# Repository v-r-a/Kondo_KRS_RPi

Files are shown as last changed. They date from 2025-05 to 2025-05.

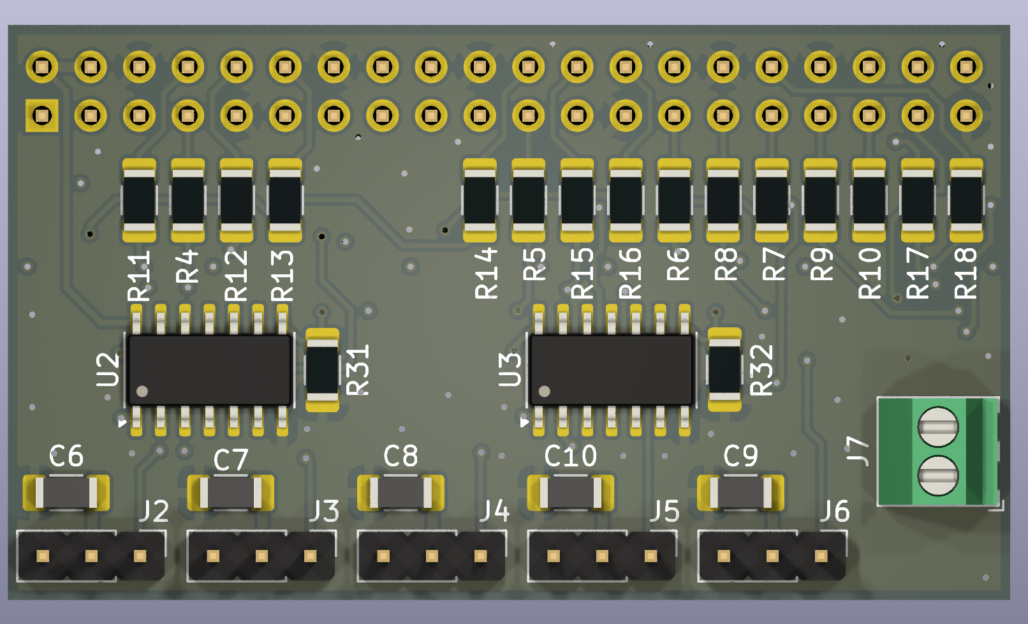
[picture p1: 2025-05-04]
hds_rpi_250121/hds_rpi_3Dtop_250121.png

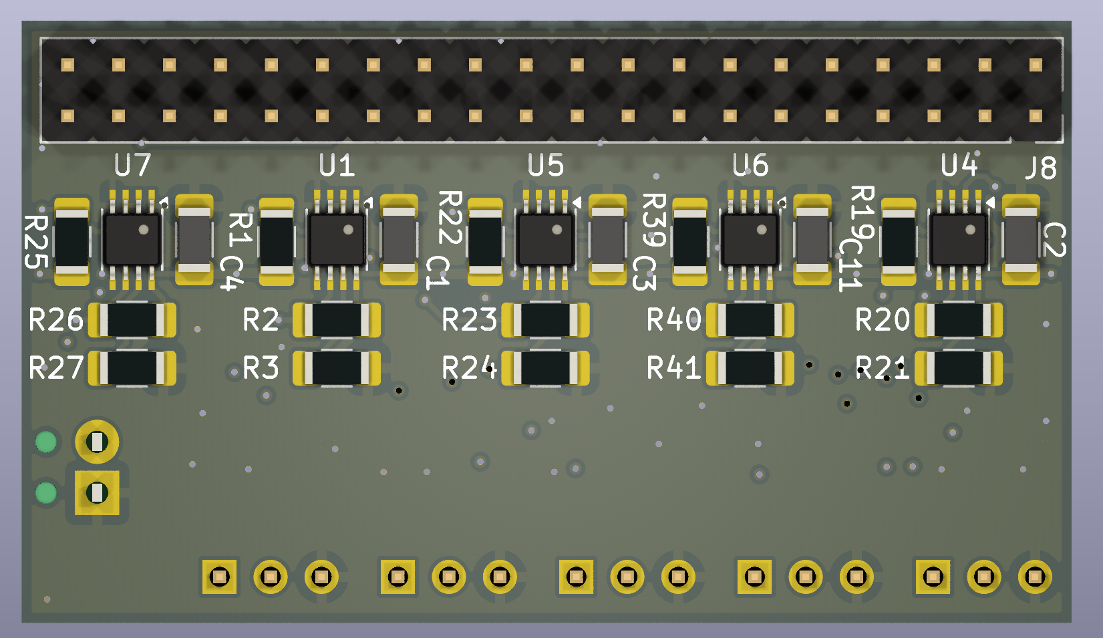
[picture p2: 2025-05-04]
hds_rpi_250121/hds_rpi_3Dbot_250121.png

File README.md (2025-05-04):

# Kondo_KRS_RPi
A Linux library for Raspberry Pi to operate the KRS motors (Kondo humanoid) using GPIO UART ports

Software dependencies: [wiringPi]([url](https://github.com/WiringPi/WiringPi))

Hardware dependencies: PCB for half-duplex communication with Kondo KRS 2552 motors. wiringPi is needed for toggling RX/TX using the tri-state buffer.

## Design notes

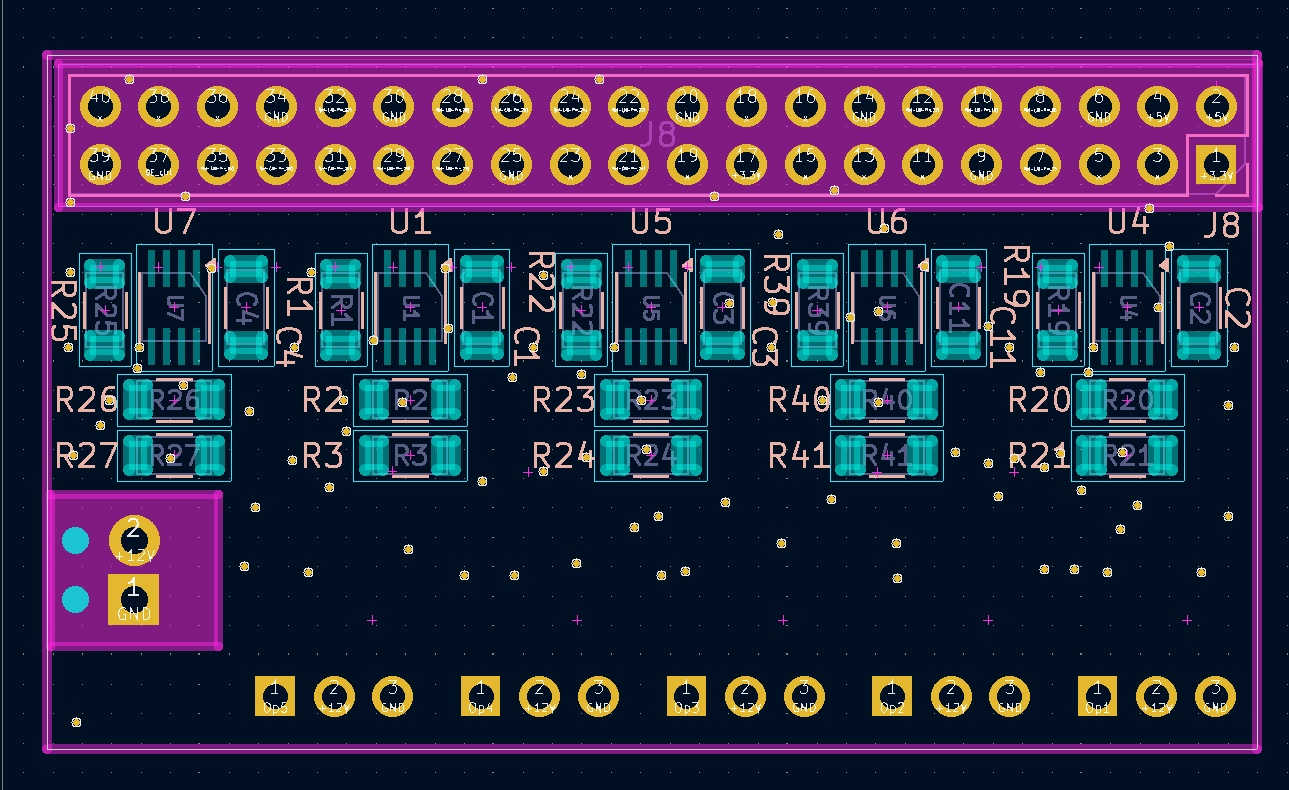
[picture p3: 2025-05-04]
hds_rpi_250121/hds_rpi_2Dbot_250121.png

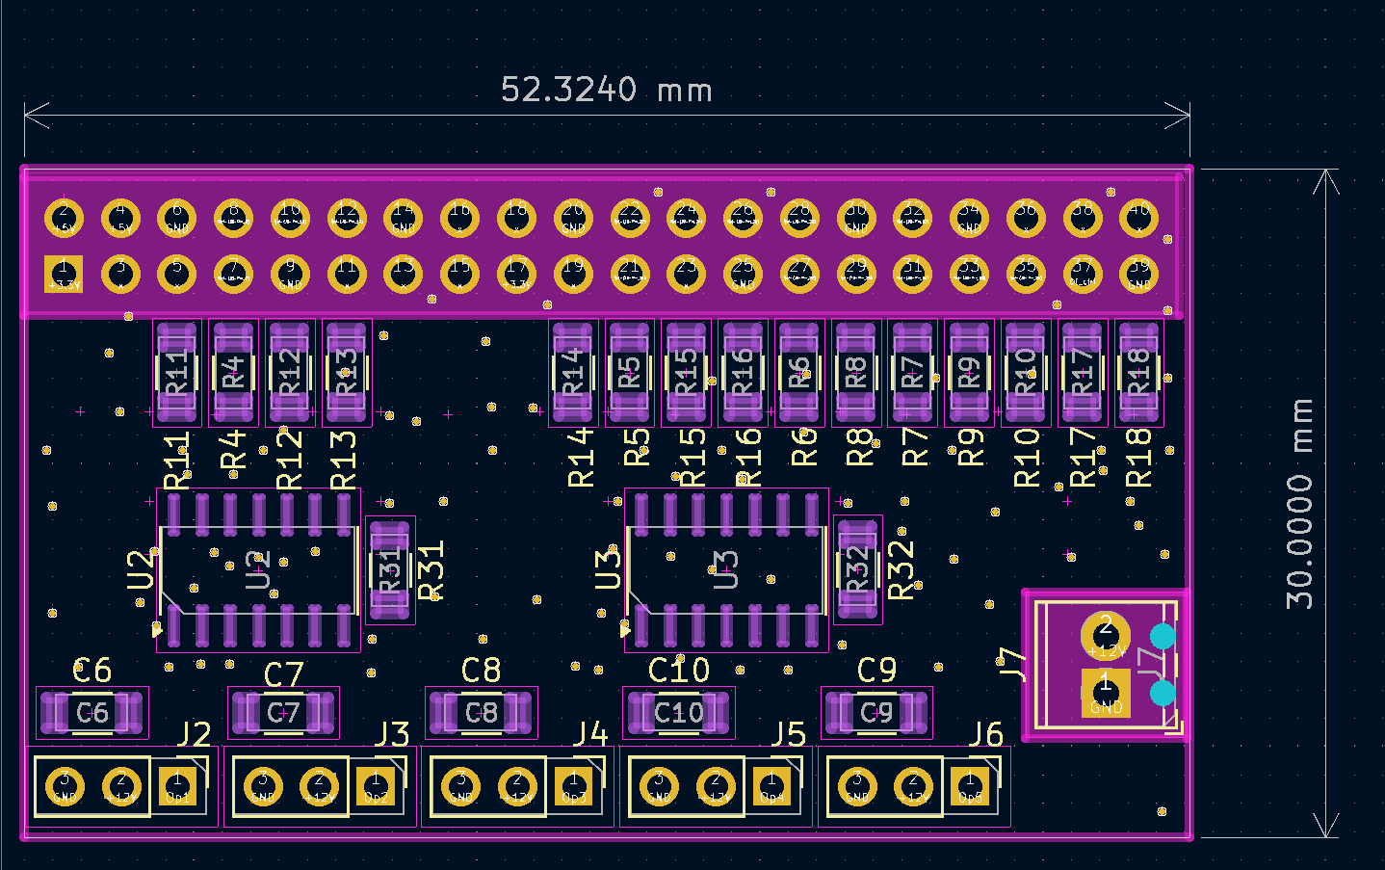
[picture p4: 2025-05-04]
hds_rpi_250121/hds_rpi_2Dtop_250121.png

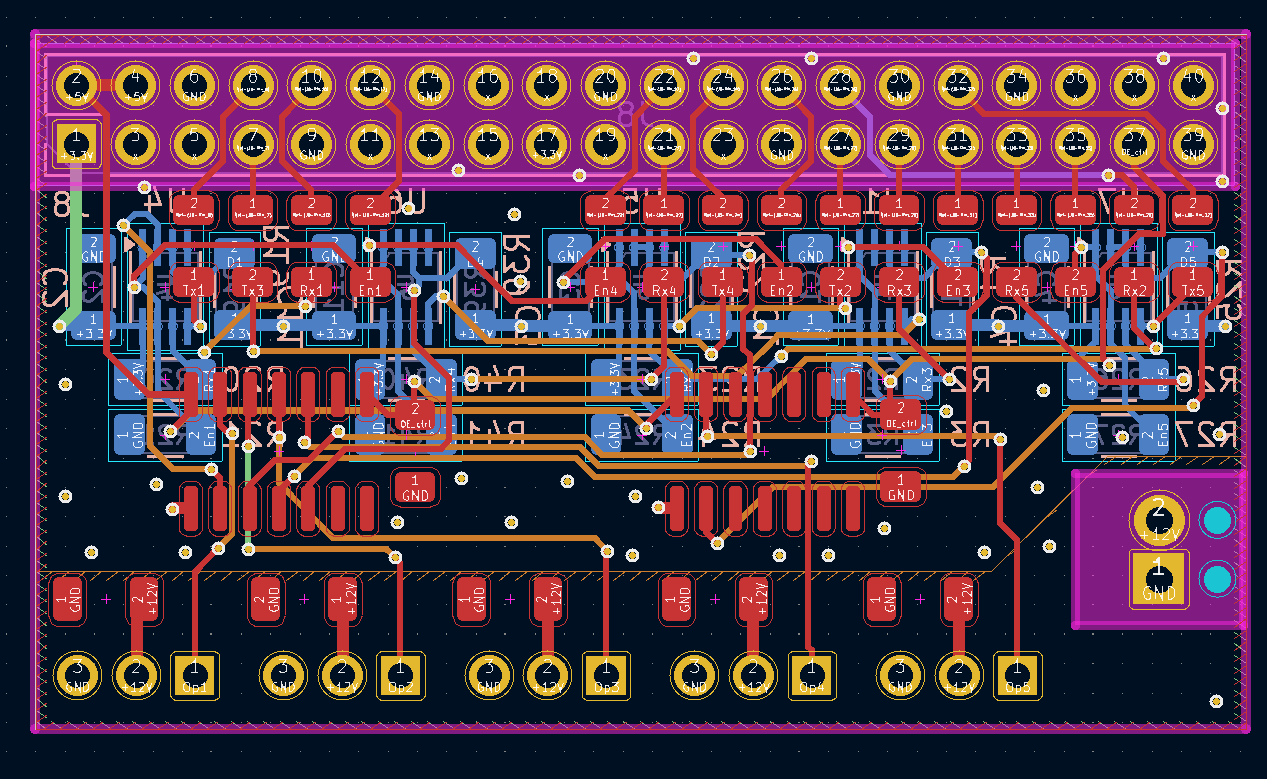
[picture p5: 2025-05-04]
hds_rpi_250121/hds_rpi_2DCU_250121.png

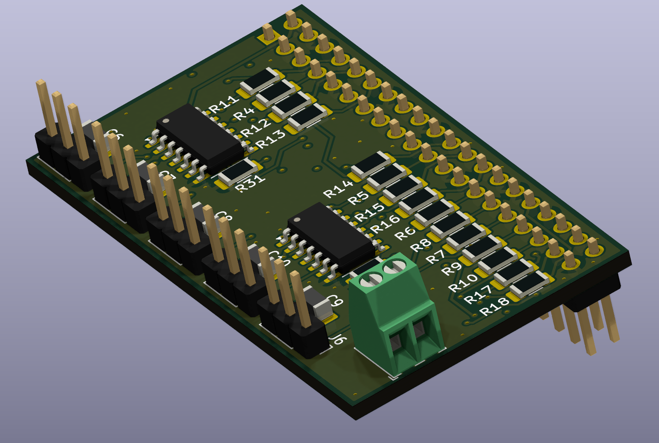
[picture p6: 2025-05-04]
hds_rpi_250121/hds_rpi_3Diso_250121.png

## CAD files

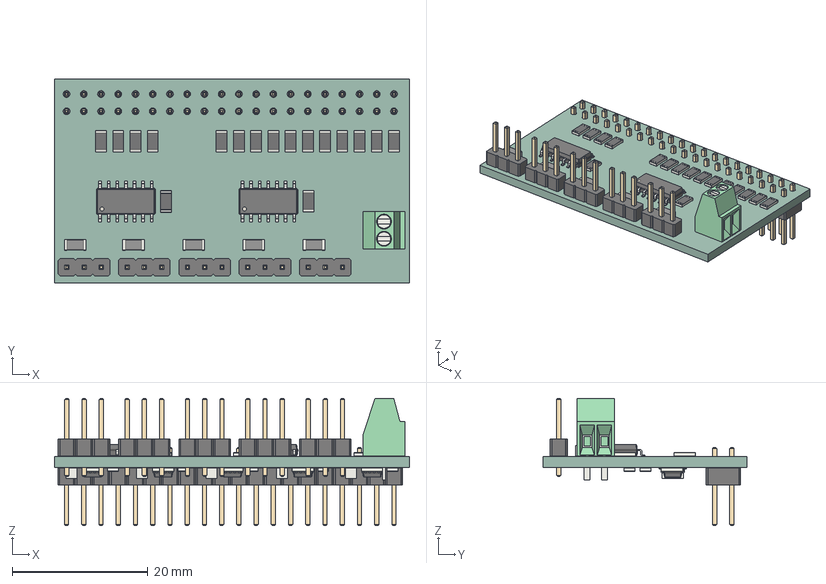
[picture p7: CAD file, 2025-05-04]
hds_rpi_250121/hds_rpi.step
52.3 x 30.0 x 18.8 mm
PinHeader_1x03_P254mm_Vertical x 5
R_1206_3216Metric x 32
L_1206_3216Metric x 10
SOIC_14_39x87mm_P127mm x 2
TerminalBlock_Phoenix_MPT_05_2_254_1x02_P254mm_Horizontal
SSOP_8_295x28mm_P065mm x 5
PinHeader_2x20_P254mm_Vertical
hds_rpi_PCB

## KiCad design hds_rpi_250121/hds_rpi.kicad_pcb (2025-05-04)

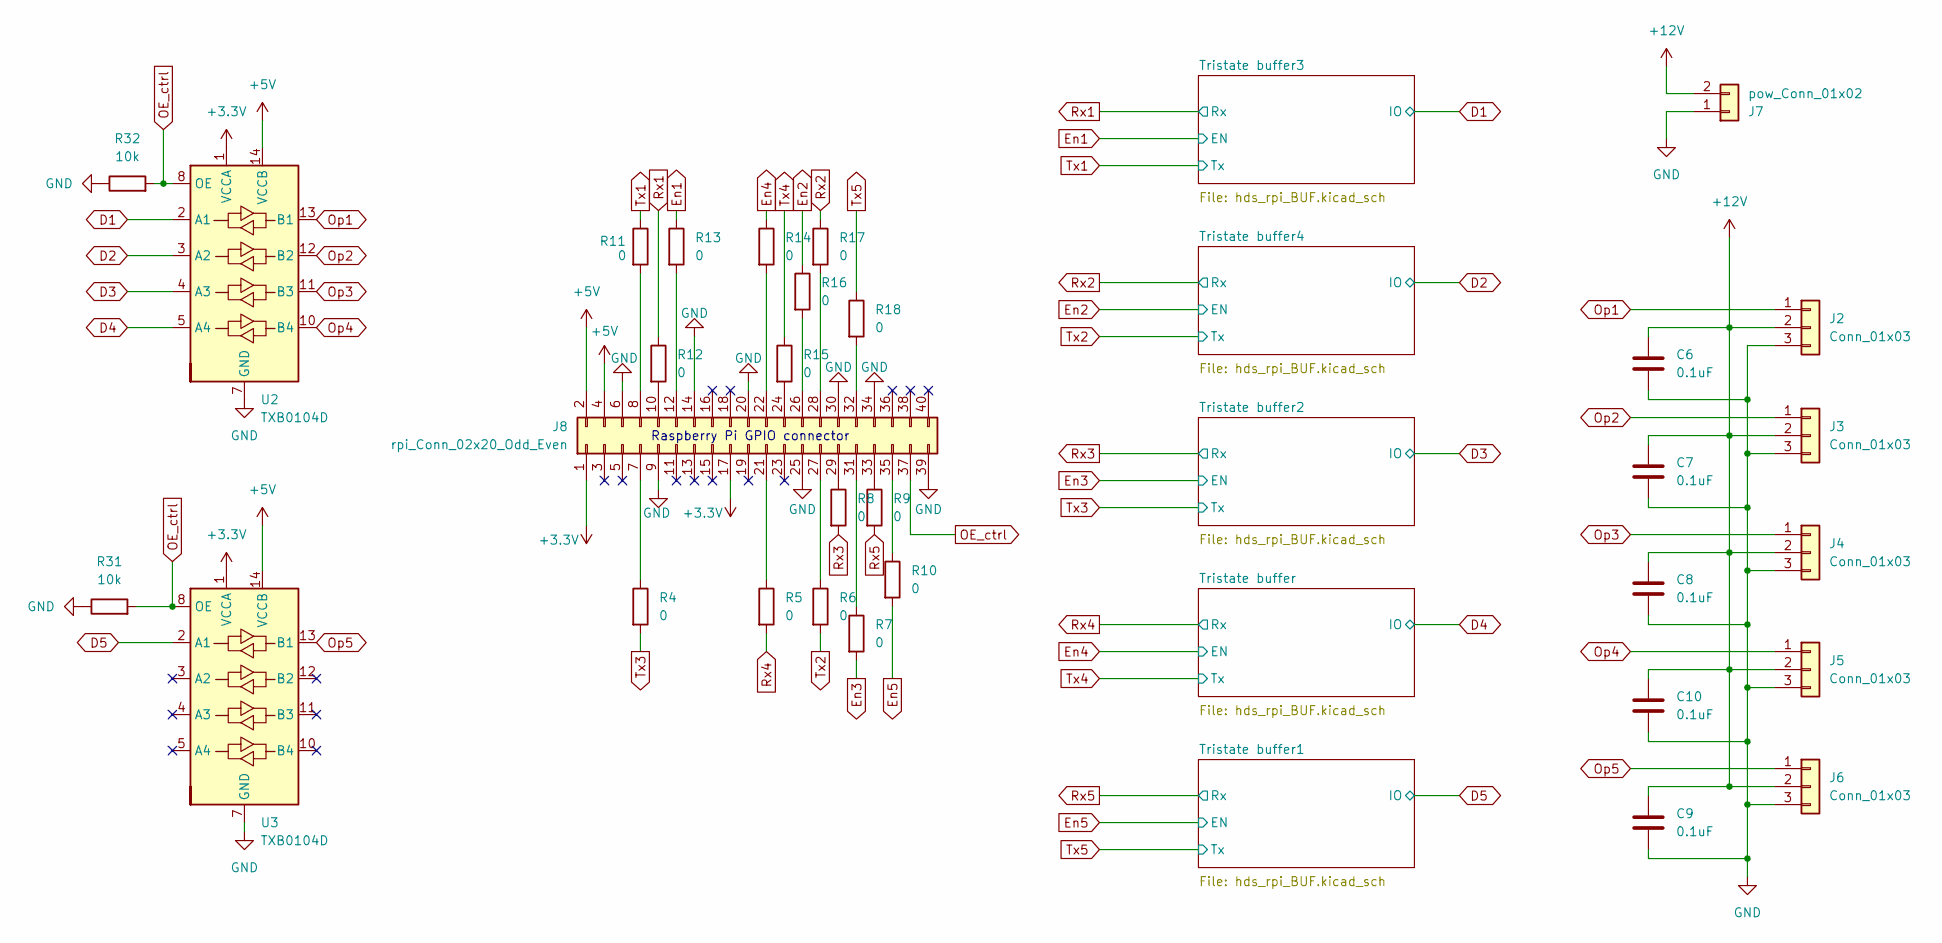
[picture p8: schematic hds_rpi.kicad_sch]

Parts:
C6, C7, C8, C9, C10: 0.1uF; L_1206_3216Metric_Pad1.22x1.90mm_HandSolder
J2, J3, J4, J5, J6: Conn_01x03; PinHeader_1x03_P2.54mm_Vertical
J7: pow_Conn_01x02; TerminalBlock_Phoenix_MPT-0,5-2-2.54_1x02_P2.54mm_Horizontal
J8: rpi_Conn_02x20_Odd_Even; Mirrored_PinHeader_2x20_P2.54mm_Vertical
R4, R5, R6, R7, R8, R9, R10, R11, R12, R13, R14, R15, R16, R17, R18: 0; R_1206_3216Metric_Pad1.30x1.75mm_HandSolder
R31, R32: 10k; R_1206_3216Metric_Pad1.30x1.75mm_HandSolder
U2, U3: TXB0104D; SOIC-14_3.9x8.7mm_P1.27mm

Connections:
+3.3V: J8.1, J8.17, U2.1 (VCCA), U3.1 (VCCA); also elsewhere on the board
+5V: J8.2, J8.4, U2.14 (VCCB), U3.14 (VCCB)
+12V: C6.2, C7.1, C8.2, C9.2, C10.2, J2.2, J3.2, J4.2, J5.2, J6.2, J7.2
D1: U2.2 (A1); also elsewhere on the board
D2: U2.3 (A2); also elsewhere on the board
D3: U2.4 (A3); also elsewhere on the board
D4: U2.5 (A4); also elsewhere on the board
D5: U3.2 (A1); also elsewhere on the board
En1: R13.1; also elsewhere on the board
En2: R16.1; also elsewhere on the board
En3: R7.2; also elsewhere on the board
En4: R14.1; also elsewhere on the board
En5: R10.2; also elsewhere on the board
GND: C6.1, C7.2, C8.1, C9.1, C10.1, J2.3, J3.3, J4.3, J5.3, J6.3, J7.1, J8.6, J8.9, J8.14, J8.20, J8.25, J8.30, J8.34, J8.39, R31.1, R32.1, U2.7 (GND), U3.7 (GND); also elsewhere on the board
unnamed: J8.7, R4.1
unnamed: J8.8, R11.2
unnamed: J8.10, R12.2
unnamed: J8.12, R13.2
unnamed: J8.21, R5.1
unnamed: J8.22, R14.2
unnamed: J8.24, R15.2
unnamed: J8.26, R16.2
unnamed: J8.27, R6.1
unnamed: J8.28, R17.2
unnamed: J8.29, R8.1
unnamed: J8.31, R7.1
unnamed: J8.32, R18.2
unnamed: J8.33, R9.1
unnamed: J8.35, R10.1
OE_ctrl: J8.37, R31.2, R32.2, U2.8 (OE), U3.8 (OE)
Op1: J2.1, U2.13 (B1)
Op2: J3.1, U2.12 (B2)
Op3: J4.1, U2.11 (B3)
Op4: J5.1, U2.10 (B4)
Op5: J6.1, U3.13 (B1)
Rx1: R12.1; also elsewhere on the board
Rx2: R17.1; also elsewhere on the board
Rx3: R8.2; also elsewhere on the board
Rx4: R5.2; also elsewhere on the board
Rx5: R9.2; also elsewhere on the board
Tx1: R11.1; also elsewhere on the board
Tx2: R6.2; also elsewhere on the board
Tx3: R4.2; also elsewhere on the board
Tx4: R15.1; also elsewhere on the board
Tx5: R18.1; also elsewhere on the board

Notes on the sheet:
Raspberry Pi GPIO connector

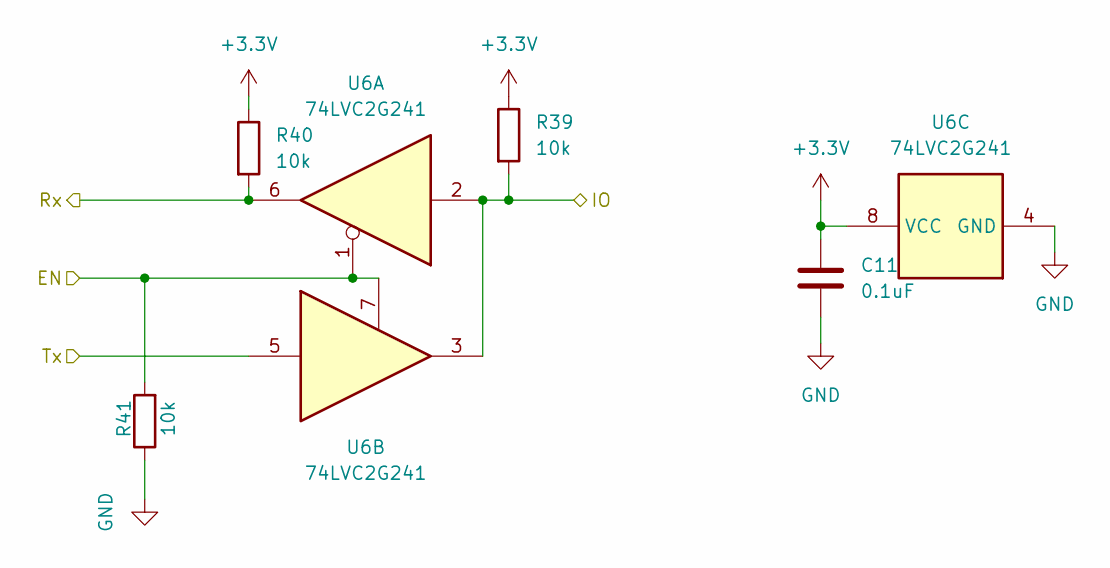
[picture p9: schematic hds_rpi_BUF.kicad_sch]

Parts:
C11: 0.1uF; L_1206_3216Metric_Pad1.22x1.90mm_HandSolder
R39, R40, R41: 10k; R_1206_3216Metric_Pad1.30x1.75mm_HandSolder
U6: 74LVC2G241; SSOP-8_2.95x2.8mm_P0.65mm

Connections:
+3.3V: C11.1, R39.1, R40.1, U6.8 (VCC); also elsewhere on the board
D4: R39.2, U6.2, U6.3; also elsewhere on the board
En4: R41.2, U6.1, U6.7; also elsewhere on the board
GND: C11.2, R41.1, U6.4 (GND); also elsewhere on the board
Rx4: R40.2, U6.6; also elsewhere on the board
Tx4: U6.5; also elsewhere on the board

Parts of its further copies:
C1, C2, C3, C4: 0.1uF; L_1206_3216Metric_Pad1.22x1.90mm_HandSolder
R1, R2, R3, R19, R20, R21, R22, R23, R24, R25, R26, R27: 10k; R_1206_3216Metric_Pad1.30x1.75mm_HandSolder
U1, U4, U5, U7: 74LVC2G241; SSOP-8_2.95x2.8mm_P0.65mm

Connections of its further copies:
+3.3V: C1.1, C2.1, C3.1, C4.1, R1.1, R2.1, R19.1, R20.1, R22.1, R23.1, R25.1, R26.1, U1.8 (VCC), U4.8 (VCC), U5.8 (VCC), U7.8 (VCC); also elsewhere on the board
D1: R19.2, U4.2, U4.3; also elsewhere on the board
D2: R22.2, U5.2, U5.3; also elsewhere on the board
D3: R1.2, U1.2, U1.3; also elsewhere on the board
D5: R25.2, U7.2, U7.3; also elsewhere on the board
En1: R21.2, U4.1, U4.7; also elsewhere on the board
En2: R24.2, U5.1, U5.7; also elsewhere on the board
En3: R3.2, U1.1, U1.7; also elsewhere on the board
En5: R27.2, U7.1, U7.7; also elsewhere on the board
GND: C1.2, C2.2, C3.2, C4.2, R3.1, R21.1, R24.1, R27.1, U1.4 (GND), U4.4 (GND), U5.4 (GND), U7.4 (GND); also elsewhere on the board
Rx1: R20.2, U4.6; also elsewhere on the board
Rx2: R23.2, U5.6; also elsewhere on the board
Rx3: R2.2, U1.6; also elsewhere on the board
Rx5: R26.2, U7.6; also elsewhere on the board
Tx1: U4.5; also elsewhere on the board
Tx2: U5.5; also elsewhere on the board
Tx3: U1.5; also elsewhere on the board
Tx5: U7.5; also elsewhere on the board

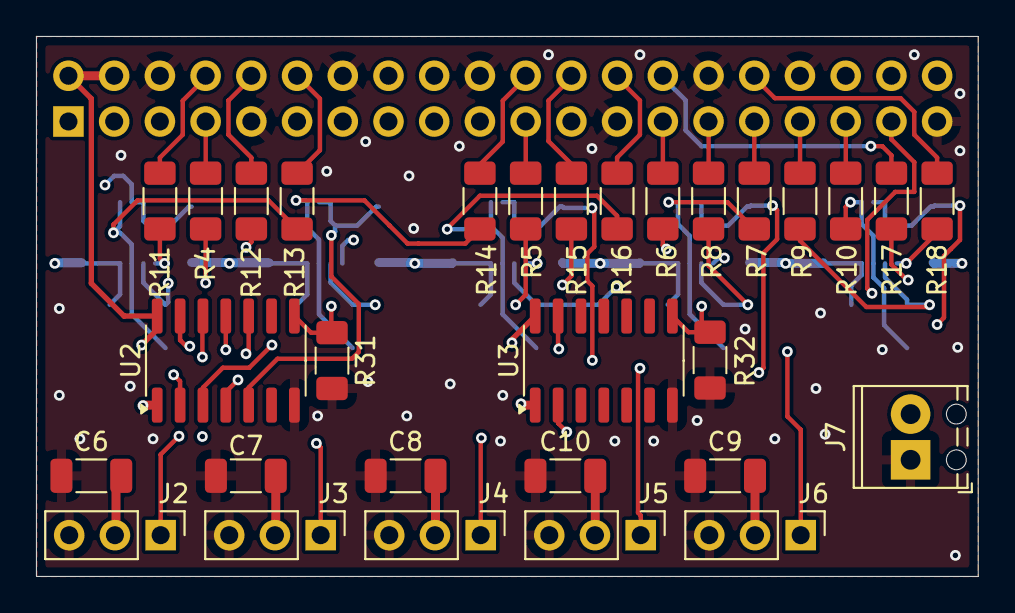
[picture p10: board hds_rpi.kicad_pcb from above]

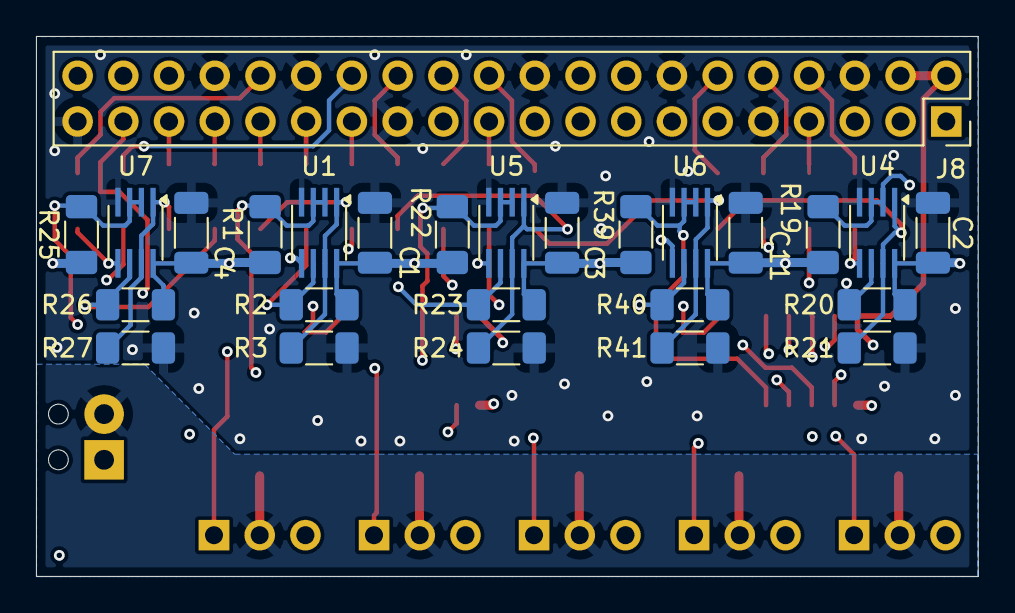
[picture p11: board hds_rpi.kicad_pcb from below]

Board: 4 copper layers, 52.3 x 30.0 mm, 56 parts (26 on the bottom side), 45 nets.

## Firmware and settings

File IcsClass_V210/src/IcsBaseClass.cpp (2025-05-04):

/**
 *	@file IcsBaseClass.cpp
 *	@brief ICS3.5/3.6 base library
 *	@author Kondo Kagaku Co.,Ltd.
 *	@date	2020/02/20
 *	@version 2.1.0
 *	@copyright &copy; Kondo Kagaku Co.,Ltd. 2017
 **/
#include <cstdio>
#include <wiringPi.h>
#include "IcsBaseClass.h"

// Servo ID range /////////////////////////////////////////////////////////////////////////////////////////////
/**
 * @brief Check if the servo ID is within range
 * @param[in] id
 * @return the ID sent
 * @retval 0xFF out of range
 **/
unsigned char IcsBaseClass::idMax(unsigned char id)
{
  if ((char)id < MIN_ID)
  {
    id = 0xFF;
  }
  if (id > MAX_ID)
  {
    id = 0xFF;
  }
  return id;
}

// Servo movable range parameter range limit setting ///////////////////////////////////////////////////////////////
/**
 * @brief Keep within the maximum and minimum value range of position data
 * @param[in] maxPos Maximum value
 * @param[in] minPos Minimum value
 * @param[in,out] val current value
 * @return Position data with limit
 **/
bool IcsBaseClass::maxMin(int maxPos, int minPos, int val)
{
  if (val > maxPos)
  {
    return false;
  }
  if (val < minPos)
  {
    return false;
  }
  return true;
}

// Angle conversion　From angle to POS/////////////////////////////////////////////////////////////////////////////////////
/**
 * @brief Convert angle data (float type) to position data
 * @param[in] deg Angle (deg) (float type)
 * @return position data
 * @retval -1 out of range
 **/
int IcsBaseClass::degPos(float deg)
{
  if (deg > MAX_DEG)
  {
    return -1;
  }
  if (deg < MIN_DEG)
  {
    return -1;
  }
  int pos = deg * 29.633;
  pos = pos + 7500;
  return pos;
}

// Angle conversion POS to angle /////////////////////////////////////////////////////////////////////////////////////
/**
 * @brief Convert position data to angle data (float type)
 * @param[in] pos position data
 * @return Angle (deg) (float type)
 * @retval #ANGLE_F_FALSE Out of range in positive direction
 * @retval -#ANGLE_F_FALSE (0x8000) Out of range in negative direction
 **/
float IcsBaseClass::posDeg(int pos)
{
  pos = pos - 7500;
  float deg = pos / 29.633;

  if (deg > MAX_DEG)
  {
    return ANGLE_F_FALSE;
  }
  if (deg < MIN_DEG)
  {
    return -ANGLE_F_FALSE;
  }

  return deg;
}

// Angle conversion x100 Angle to POS///////////////////////////////////////////////////////////////////////////////
/**
 * @brief Convert angle data x100 (int type) to position data
 * @param[in] deg Angle (deg x100) (int type)
 * @return Converted position data
 * @retval -1 out of range
 **/
int IcsBaseClass::degPos100(int deg)
{
  if (deg > MAX_100DEG)
  {
    return -1;
  }
  if (deg < MIN_100DEG)
  {
    return -1;
  }
  long a = ((long)deg * 2963) / 10000;
  int pos = a + 7500;
  return pos;
}

// Angle conversion x100 POS to angle///////////////////////////////////////////////////////////////////////////////
/**
 * @brief Convert position data to angle data (int type)
 * @param[in] pos position data
 * @return Angle (deg x100) (int type)
 * @retval #ANGLE_I_FALSE Out of range in positive direction
 * @retval -#ANGLE_I_FALSE Out of range in negative direction
 **/
int IcsBaseClass::posDeg100(int pos)
{
  long a = pos - 7500;
  int deg = (a * 1000) / 296;

  if (deg > MAX_100DEG)
  {
    return ANGLE_I_FALSE;
  }
  if (deg < MIN_100DEG)
  {
    return -ANGLE_I_FALSE;
  }
  return deg;
}

// Servo angle set //////////////////////////////////////////////////////////////////////////////////////////
/**
 * @brief Change the angle of the servo motor
 * @param[in] id Servo motor ID number
 * @param[in] pos position data
 * @return position data
 * @retval -1 out of range, communication failure
 **/
int IcsBaseClass::setPos(unsigned char id, unsigned int pos)
{
  unsigned char txCmd[3];
  unsigned char rxCmd[3];
  unsigned int rePos;
  bool flg;

  if ((id != idMax(id)) || (!maxMin(MAX_POS, MIN_POS, pos))) // When out of range
  {
    return ICS_FALSE;
  }

  txCmd[0] = 0x80 + id;             // CMD
  txCmd[1] = ((pos >> 7) & 0x007F); // POS_H
  txCmd[2] = (pos & 0x007F);        // POS_L

  // sending and receiving
  flg = synchronize(txCmd, sizeof txCmd, rxCmd, sizeof rxCmd);
  if (flg == false)
  {
    return ICS_FALSE;
  }

  rePos = ((rxCmd[1] << 7) & 0x3F80) + (rxCmd[2] & 0x007F);

  return rePos;
}

// Servo free mode ///////////////////////////////////////////////////////////////////////////////////////
/**
 * @brief Sets the servo motor to a free (weak) state.
 * @param[in] id Servo motor ID number
 * @return position data
 * @retval -1 out of range, communication failure
 **/
int IcsBaseClass::setFree(unsigned char id)
{
  unsigned char txCmd[3];
  unsigned char rxCmd[3];
  unsigned int rePos;
  bool flg;

  if (id != idMax(id)) // When out of range
  {
    return ICS_FALSE;
  }

  txCmd[0] = 0x80 + id; // CMD
  txCmd[1] = 0;
  txCmd[2] = 0;

  // sending and receiving
  flg = synchronize(txCmd, sizeof txCmd, rxCmd, sizeof rxCmd);
  if (flg == false)
  {
    return ICS_FALSE;
  }

  rePos = ((rxCmd[1] << 7) & 0x3F80) + (rxCmd[2] & 0x007F);

  return rePos;
}

// Stretch value write 1 to 127 /////////////////////////////////////////////////////////////////////////////////
/**
 * @brief Write the servo motor stretch (holding force) value
 * @param[in] id Servo motor ID number
 * @param[in] strc Stretch data (1 to 127)
 * @return Written stretch data
 * @retval -1 Communication failure
 * @note Stretch writing 1-127 1 (weak) 127 (strong)
 **/
int IcsBaseClass::setStrc(unsigned char id, unsigned int strc)
{
  unsigned char txCmd[3];
  unsigned char rxCmd[3];
  unsigned int reData;
  bool flg;

  if ((id != idMax(id)) || (!maxMin(MAX_127, MIN_1, strc))) // When out of range
  {
    return ICS_FALSE;
  }

  txCmd[0] = 0xC0 + id; // CMD
  txCmd[1] = 0x01;      // SC stretch
  txCmd[2] = strc;      // stretch

  // sending and receiving
  flg = synchronize(txCmd, sizeof txCmd, rxCmd, sizeof rxCmd);
  if (flg == false)
  {
    return ICS_FALSE;
  }
  reData = rxCmd[2];

  return reData;
}

// Speed value writing 1 to 127 ///////////////////////////////////////////////////////////////////////////////////
/**
 * @brief Change the speed (output) of the servo motor
 * @param[in] id Servo motor ID number
 * @param[in] spd Speed data (1 to 127)
 * @return Written speed data
 * @retval -1 Communication failure
 * @note Speed writing 1-127 1(slow) 127(fast)
 **/
int IcsBaseClass::setSpd(unsigned char id, unsigned int spd)
{
  unsigned char txCmd[3];
  unsigned char rxCmd[3];
  unsigned int reData;
  bool flg;

  if ((id != idMax(id)) || (!maxMin(MAX_127, MIN_1, spd))) // When out of range
  {
    return ICS_FALSE;
  }

  txCmd[0] = 0xC0 + id; // CMD
  txCmd[1] = 0x02;      // SC speed
  txCmd[2] = spd;       // speed

  // sending and receiving
  flg = synchronize(txCmd, sizeof txCmd, rxCmd, sizeof rxCmd);
  if (flg == false)
  {
    return ICS_FALSE;
  }

  reData = rxCmd[2];

  return reData;
}
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

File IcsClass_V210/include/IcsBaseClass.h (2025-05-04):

/**
*@file IcsBaseClass.h
*@brief ICS3.5/3.6 bace library header file
*@author Kondo Kagaku Co.,Ltd.
*@date 2017/12/27
*@version 2.1.0
*@copyright Kondo Kagaku Co., Ltd. 2020

*@mainpage Overview of IcsClass
*This library is for operating Kondo Scientific robot servos (KRS series). <br>
*Compatible with ICS3.5 and ICS3.6. <br>
*Currently designed to be used with Arduino products. <br>
*For usage and details, please see our website below. <br>
*<A HREF="http://kondo-robot.com/">http://kondo-robot.com/</A><br>
*If you have any problems, please contact us by referring to our website. <br>

*@par change history
*@par 2020/02/20 Ver 2.1.0
*-Change getStr in keywords.txt to getStrc
*-Change synchronize from protected to public //Because I wanted to use it externally
*-Implementation of ID command
*@par 2017/12/27 ver 2.0.0
*-Separate the communication part of ICSClass. Create IcsBaseClass.
*-"IcsHardSerialClass" which uses Serial
*<br> Derive "IcsSoftSerialClass" from IcsBaseClass using SoftSerial
*-Since SoftSerial could not use parity and the timing did not match, I created "KoCustomSoftSerial"
*@par 2016/12/27　ver 1.0.0
*-Initial distribution
**/

#ifndef __ics_Base_Servo_h__
#define __ics_Base_Servo_h__

// IcsBaseClass class ////////////////////////////////////////////////////
/**
 *@class IcsBaseClass
 *@brief Kondo Scientific's ICS 3.5/3.6 Base class for operating servo motors via microcontroller
 *@brief Create a base class to use Raspberry Pi UART
 **/
class IcsBaseClass
{
  // Fixed value (published)
public:
  // Servo ID range //////////////////////////////////////
  static constexpr int MAX_ID = 31; ///< Maximum value of servo ID
  static constexpr int MIN_ID = 0;  ///< Minimum value of servo ID

  // Servo maximum and minimum limit values

  static constexpr int MAX_POS = 11500; ///< Servo position maximum value

  static constexpr int MIN_POS = 3500; ///< Servo position minimum value
  static constexpr int ICS_FALSE = -1; ///< Value when ICS communication etc. fails

  // Fixed value (undisclosed)
protected:
  static constexpr float ANGLE_F_FALSE = 9999.9; ///< When calculating the angle, if it is not within the range, set it to 999.9 (if it is on the negative side, add a minus)
  static constexpr int ANGLE_I_FALSE = 0x7FFF;   ///< When calculating the angle, if it is not within the range, set it to 0x7FFF (if it is on the negative side, add a minus)

  // Each parameter setting range
  static constexpr int MAX_127 = 127; ///< Maximum value of parameter

  static constexpr int MAX_63 = 63; ///< Maximum value of parameter (current value)

  static constexpr int MIN_1 = 1;         ///< Minimum value of parameter
                                          // static const float MAX_DEG = 135.0;
  static constexpr float MAX_DEG = 180.0; ///< Maximum value of angle

  // static const float MIN_DEG = -135.0;
  static constexpr float MIN_DEG = -180.0; ///< Maximum value of angle

  // static const int MAX_100DEG = 13500;
  static constexpr int MAX_100DEG = 18000; ///< Maximum value of angle (x100)

  // static const int MIN_100DEG = -13500;
  static constexpr int MIN_100DEG = -18000; ///< Minimum value of angle (x100)

  // type definition in class
public:
  // constructor, destructor
  virtual ~IcsBaseClass() {}

public:
  // constructor

  // variable
public:
protected:
  // function

  // data transmission/reception
public:
  // Data transmission/reception //////////////////////////////////////////////////////////////////////////////////////////////
  /**
   *@brief Sending and receiving ICS communication
   *@param[in,out] *txBuf
   *@param[in] txLen
   *@param[out] *rxBuf Receive storage buffer
   *@param[in] rxLen Number of received data
   *@retval true Communication successful
   *@retval false Communication failure
   *@attention Please note that the number of sent data and received data varies depending on the command.
   *@attention This function must be written externally.
   **/
  virtual bool synchronize(unsigned char *txBuf, unsigned char txLen, unsigned char *rxBuf, unsigned char rxLen) = 0;

  // servo related
public:
  // Servo positioning settings
  int setPos(unsigned char id, unsigned int pos); // Target value setting
  int setFree(unsigned char id);                  // Servo weakness + reading current value

  // Write various parameters
  int setStrc(unsigned char id, unsigned int strc);  // Stretch writing 1 to 127 1 (weak) <=> 127 (strong)
  int setSpd(unsigned char id, unsigned int spd);    // Speed writing 1 to 127 1(slow) <=> 127(fast)
  int setCur(unsigned char id, unsigned int curlim); // Write current limit value 1 to 63 1 (low) <=> 63 (high)
  int setTmp(unsigned char id, unsigned int tmplim); // Temperature upper limit write 1 to 127 127 (low temperature) <=> 1 (high temperature)

  // Read various parameters
  int getStrc(unsigned char id); // Stretch reading 1 to 127 1 (weak) <=> 127 (strong)
  int getSpd(unsigned char id);  // Speed reading 1 to 127 1(slow)<=> 127(fast)
  int getCur(unsigned char id);  // Read current value 63←0 | 64→127
  int getTmp(unsigned char id);  // Read current temperature 127 (low temperature) <=> 0 (high temperature)
  int getPos(unsigned char id);  // Read current position *Valid for ICS3.6 or later

  int getID();
  int setID(unsigned char id);

protected:
  // Servo ID limit
  unsigned char idMax(unsigned char id);

  ////Servo movable range parameter range limit setting
  bool maxMin(int maxPos, int minPos, int val);

  // Angle related
public:
  // Angle conversion Convert from POS to angle
  static int degPos(float deg);
  // Angle conversion Convert from angle to POS
  static float posDeg(int pos);

  // Angle conversion x100 Convert from POS to angle
  static int degPos100(int deg);
  // Angle conversion x100 Convert from angle to POS
  static int posDeg100(int pos);
};
#endif
